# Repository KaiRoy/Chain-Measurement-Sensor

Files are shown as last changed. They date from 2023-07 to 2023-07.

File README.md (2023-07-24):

# Chain-Measurement-Sensor
The focus of this project was to create a Sensor that measures the wear of a chain for our Senior design course. The project partner for this project was the Hyster-Yale Group.

<!-- Insert Image Here -->

<!-- LINK SUMMARY VIDEO SOMEWHERE IN THE README!! -->

## Table of Contents

- [Description](#description)
- [Design](#design)
- [Current State](#current-state-of-the-project)
- [Post Project Notes](#post-project-notes)
- [Installation](#installation) <!-- Should I have Installation and Usage above or below the Design, Current State, Changes, etc? -->
- [Usage](#usage)
- [Credits](#credits)
- [License](#license)

## Description

The goal of this project is to create a chain elongation monitor for the Hyster-Yale Group that will automatically detect a worn lift chain and notify an operator to replace said chain. Chains, especially lifting chains, need to be frequently inspected to ensure they meet specifications. A 3% increase in a chain’s length can reduce its lifting capacity by 15%. This can become a dangerous hazard if out-of-spec chains are not caught. 

Currently, this inspection is either done by hand or by expensive third party devices, thus the creation of a cheap electronic alternative is very desirable. We plan to use three pairs of IR LEDs and IR receivers that will act as our sensors. These pairs will be situated in such a way that the IR “beam” will break when a chain link passes the sensor and reconnect in the gap between chain links. One pair will be used to measure the speed, while the other two will measure the “stretch” of the chain by recording the time difference between activations and calculating a length measurement.

In addition to the sensors, the device will consist of a power circuit to convert a Forklift’s 24V power into 5Vs, a CAN communication circuit, and a microcontroller to calculate the elongation based on the sensors and send those measurements via the CAN Circuit to the Hyster Vehicle. We chose an ATTiny814 for our microcontroller as it is a relatively small and cheap microcontroller and is capable of performing necessary functions, such as basic calculations and time measurement. 

Our project partner has specified that the device needs to meet four requirements:
 - The device needs to measure chain “stretch” (wear) within ±5% of the actual measurement.
 - The device, specifically the electronics, need to cost less than $15 or less at a production quantity of 15,000/yr
 - The device need to be robust enough to survive abrasive (high chain wear) applications
 - The device needs to communicate using the CAN communication protocol

At the end of our project, we were able to meet 3 of the 4 project partner requirements with the accuracy requirement being the one that was not met. This is mostly due to not having enough time to finish experimenting and debugging the code. With better time management and planning, we would have been able to finish the development of our code and could have met the final requirement.

## Designs

For the design portion of this project, the system's design was split into eight blocks with each person handling the design for two blocks. Adam handled the design of the Power Filter and the Power Regulator Blocks. Tianhao designed the Microcontroller and CAN Communication Circuits. The sensor and PCB blocks were handled by Kai. The code and the enclosure blocks were designed by Corbin. 

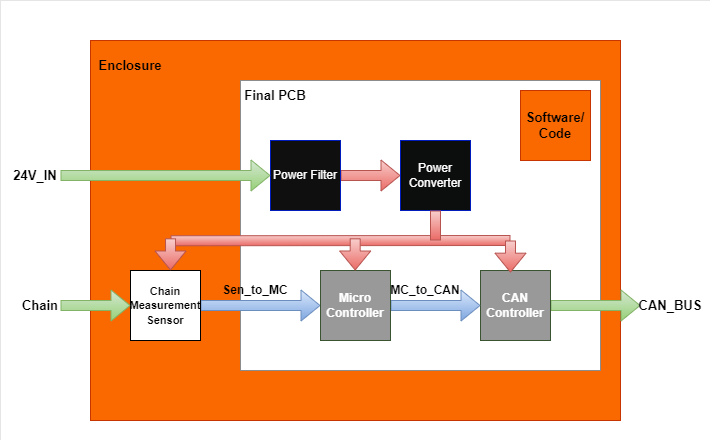
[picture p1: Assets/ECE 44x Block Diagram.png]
System Block Diagram


<!-- Power Blocks -->
The power converter block is based on an application schematic from the MC34063A-E datasheet to be used as a step-down converter. This block accomplishes the goal of reducing voltage and increasing current from 25V to 5V and current up to 500mA. The goal is to make the voltage and current levels safe for our microcontroller, CAN controller, and sensors to be used properly without overheating. The block contains the MC34063A/E chip itself, IN5819 Zener diode, three resistors (two are external to control the voltage output), three capacitors, and one inductor.

The power filter block is based on the LC filter schematic from [Digikey’s online LC filter calculator](https://www.digikey.com/en/resources/conversion-calculators/conversion-calculator-low-pass-and-high-pass-filter) to be used as a first order LC filter. This block accomplishes the goal of reducing frequency down to a fixed value of about less than 16kHz. This is to ensure that our high noise level of frequency is reduced so that our microcontroller and sensors can operate effectively. The block contains one inductor and one capacitor.

<!-- CAN Controller-->
The can block is built with one of the most practical stand-alone CAN controllers, MCP 2515 as the core. This module achieves the goal of communicating with Hyster Forklift’s electronics via 5 V digital serial signal. After achieving this goal, we can connect our device to the forklift with only two wires, so that the forklift can receive any information accurately. In this block, in addition to MCP 2515, we will also use TJA 1051 as the transceiver of the block to transmit or receive information transmitted through the CAN bus, an 8M Hz crystal oscillator as a bit rate regulator, an LED as an indicator, and some resistors and capacitors to stabilize the voltage and current of the part. In addition, we will also add two terminal block connectors to allow the output of the signal to adapt to more kinds of wires.

<!-- Micrcontroller -->
The Microcontroller block to be used in this project is the ATtiny 814. The module will be responsible for collecting and analyzing signals from the sensor, as well as controlling the operation of the signal transmitter. With the ATtiny 814, the project aims to achieve certain targets, such as measuring chain "stretch" within +/- 5% of the actual measurement, costing less than $10 at a production quantity of 15,000/yr, and outputting an analog (5V) or digital signal (CAN or other serial protocol signal).

<!-- Sensors -->
The Sensor block is implemented using three IR Breakbeam sensors. This document provides an overview of the overall block function including interface properties and a schematic, verification for the design in the form of a step-by-step testing process, and support for the validity of the design in the form of outside research and numerical justification addressing individual properties.

One sensor is placed in the ‘middle’ middle of the device and will be for measuring the speed of the Chain, while two sensors will be placed on the outer edges of the device and will be used for measuring/detecting the elongation of the chain.

The measurement of speed can be done by measuring the time difference between sensor activation as a chain link crosses the two central sensors and calculating the speed with that delta and the chain link length. For the elongation measurement/monitoring, the outer two sensors are placed with a specific distance between them, X amount of chain links. If positioned correctly, the two sensors will activate simultaneously with a chain that is not elongated and activates with some time delta with a chain that is elongated. This time delta coupled with the calculated speed can provide an estimate for the elongation measurement.

<!-- PCB -->
The Final PCB contains most of the circuits for all of the electronics blocks of the system. These circuits include the Power Filter, Power Converter, Microcontroller, and CAN Controller Blocks. This means that all of the outward-facing interfaces for these blocks, such as the sensor, power, and CAN connectors, are the interfaces for this block. 

<!-- Enclosure -->
The enclosure for this project will be a durable Pelican Case, created and distributed by the Pelican company. This ensures that our enclosure will be consistent, professionally made, and strong enough to protect our fragile components from the dangerous environment they will have to be in. Additionally, a piece of acrylic will be laser cut to allow for the mounting of the PCB and the guiding of wires through the walls of the enclosure, which will have holes cut into it.

## Current State of the Project

By the end of the project, we had a mostly working system. 

## Post Project Notes

## Installation

What EDA libraries and files are needed for this project?
- Various Component Libraries

<!--
## Usage

Provide instructions and examples for use. Include screenshots as needed.

To add a screenshot, create an `assets/images` folder in your repository and upload your screenshot to it. Then, using the relative filepath, add it to your README using the following syntax:

    ```md
    ![alt text](assets/images/screenshot.png)
    ```

## Features

If your project has a lot of features, list them here.

## Tests

-->

## Credits

List your collaborators, if any, with links to their GitHub profiles.
- Kai Roy
- 

If you used any third-party assets that require attribution, list the creators with links to their primary web presence in this section.
-

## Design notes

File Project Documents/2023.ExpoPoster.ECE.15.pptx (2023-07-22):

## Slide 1

ECE.15

Engineering Requirements

The System will…
- PCB - Have a single PCB that is no larger than 6 inches squared and contains all non-sensor circuits.
- Power Input - Operate on 24VDC with up to 3Vpp of noise and 500mA peak of current.
- Project Partner Checkoff - Be approved by a Hyster-Yale electrical engineer (project partner).
- Robust Enclosure - Continue to operate at designed accuracy after 250 chain rotations.
- Sensor Accuracy - Measure chain “stretch” within +/- 5% of the actual value.
- Signal Output - Communicate with the Hyster Forklift’s electronics using a 5V digital serial signal.
- System Cost - Cost less than $15 at a production quantity of 15,000/yr, including the enclosure.
- Water Resistance - Function normally after applying a 12oz bottle of water from above.

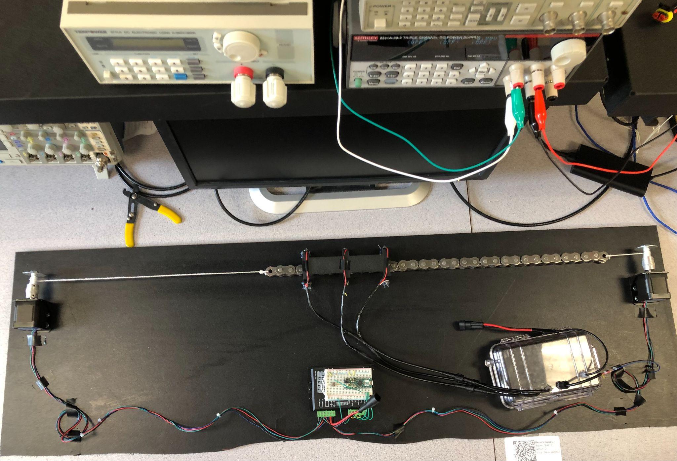
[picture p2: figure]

Fig. 4. Test bench used to determine the accuracy and durability of the system

Forklift Chain “Stretch” Monitor

Non-Contact Sensor to Determine Chain Wear for Heavy Duty Applications

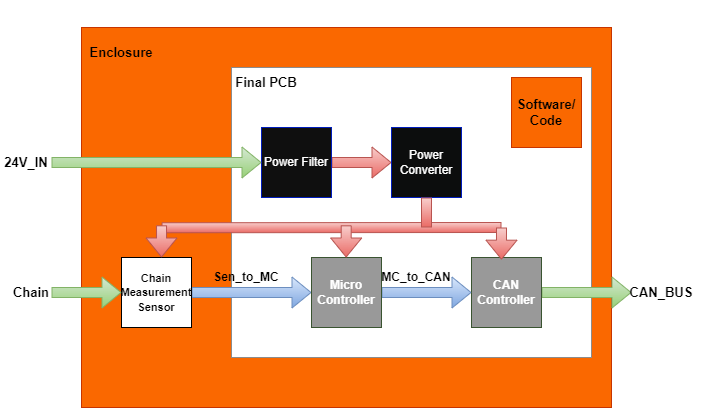
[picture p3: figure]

Fig. 1. Block diagram of the system

Project Summary

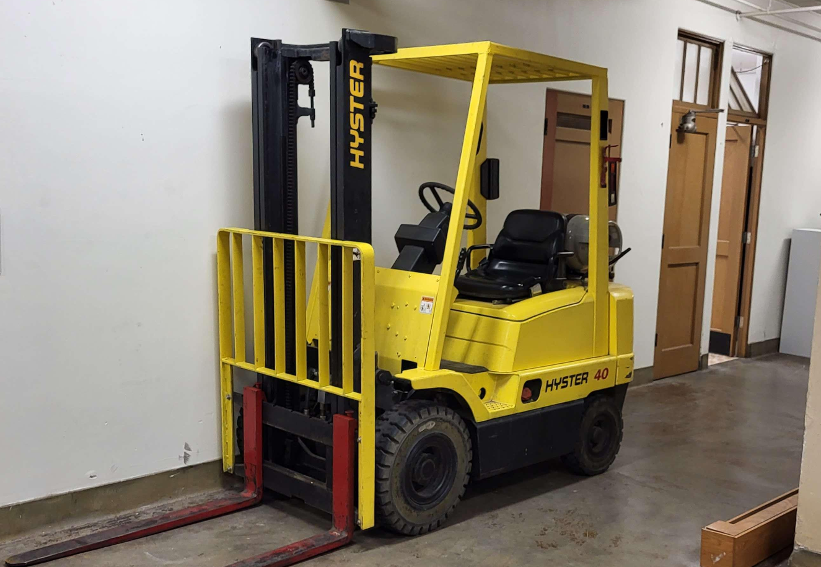
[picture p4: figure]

Fig. 5. Hyster Forklift

Our project is intended to determine whether it is feasible to create a reliable chain wear detection device that is economical. Hyster-Yale currently uses chain wear detection devies and our goal was to create a proof of concept that Hyster-Yale can obtain and improve upon.

CAN Controller

- The Controller Area Network (CAN) is one way of facilitating communication between electronic components
- CAN is a standard communication system in vehicles and allows for different sensors and components to communicate on the same line/bus in a priority-driven manner
- Many modern vehicles, and importantly Hyster Yale forklifts, use CAN controls
- Information from more crucial components is transmitted before other, less important devices all on the same network

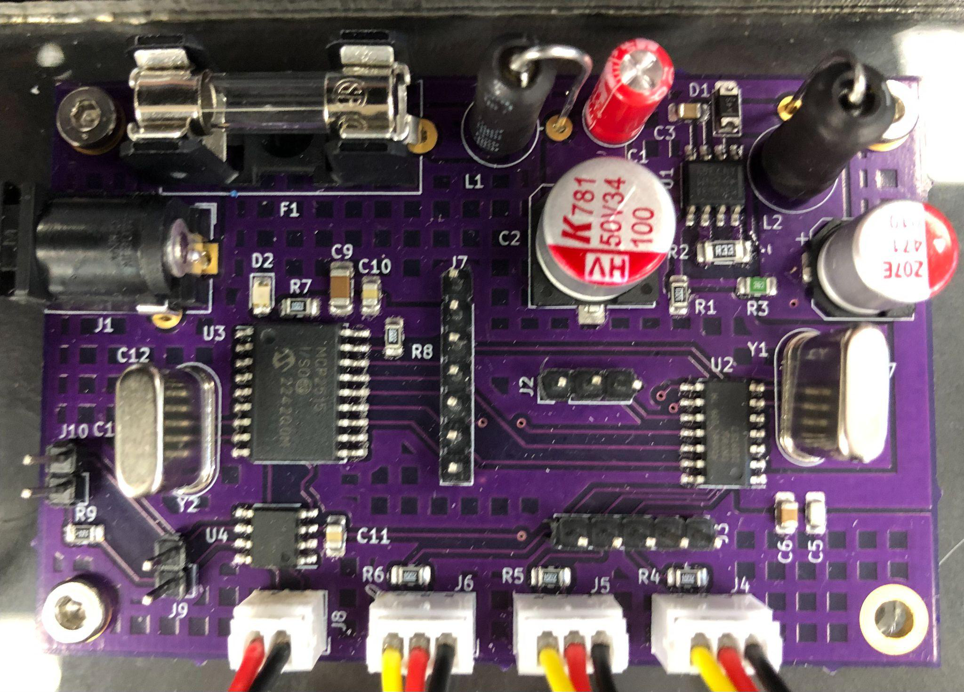
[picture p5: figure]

Fig. 2. Assembled PCB

Chain Measurement Sensor

- Three IR Break beam Sensors are used to measure Chain Elongation
- One sensor is used to measure speed, which the others are used to measure the elongation
- The timing difference between the sensors coupled with the speed gives us the elongation
- A 3D Bracket was designed for the sensors to keep the distance between them both constant and known for the measurement calculations

Enclosure

- Our enclosure consists of a pelican case with an acrylic plate for the custom PCB and holes drilled and then sealed to allow for waterproof cables to be added to the system. These cables connect to the Power, CAN, and sensors.

Power Filter/Converter

- Power supply with input from 24V battery
- Operates between 21-27VDC and up to but not including 500mA of current
- Uses a step-down converter (buck converter) to step down voltage and filter (LC) noise from the battery
- Efficiency rated between 66-80%. Efficiencies vary based on current
- Can replace fuse for circuit protection from current spikes from the battery

Team Members

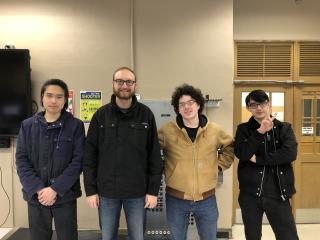
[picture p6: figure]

Fig. 6. All four members

(From left to right)
Tianhao Lin:
Microcontroller/CAN Controller Designer
lintia@oregonstate.edu
Adam Grzelewski:
Power Converter/Filter Designer
grzelewa@oregonstate.edu
Corbin Krecklow:
Programmer and Enclosure Designer
kreckloc@oregonstate.edu
Kai Roy:
Sensor and PCB Design
kaikurisakaroy@gmail.com

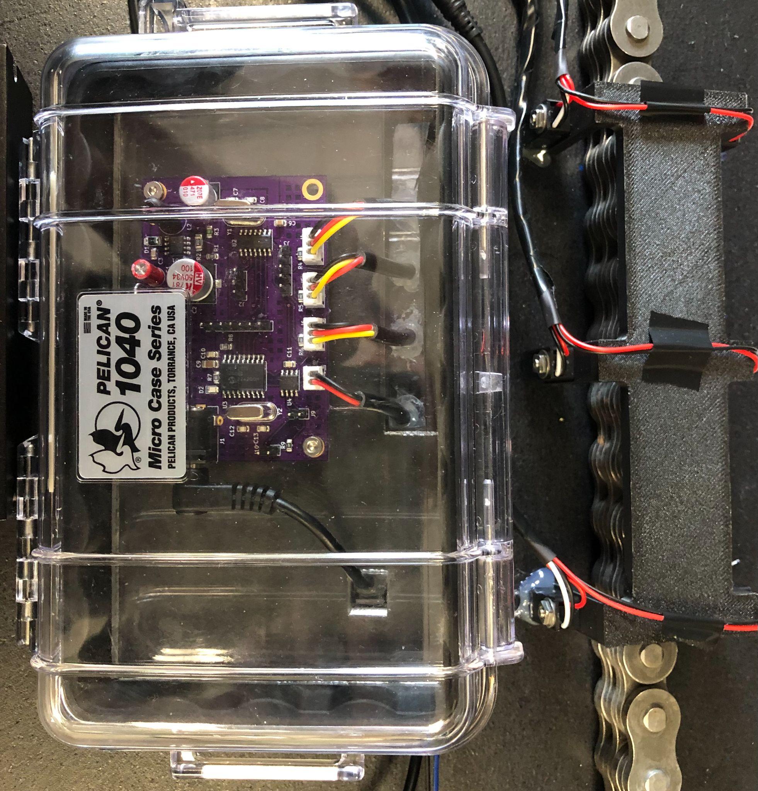
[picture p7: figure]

Fig. 3. Sensors bracket and PCB enclosure

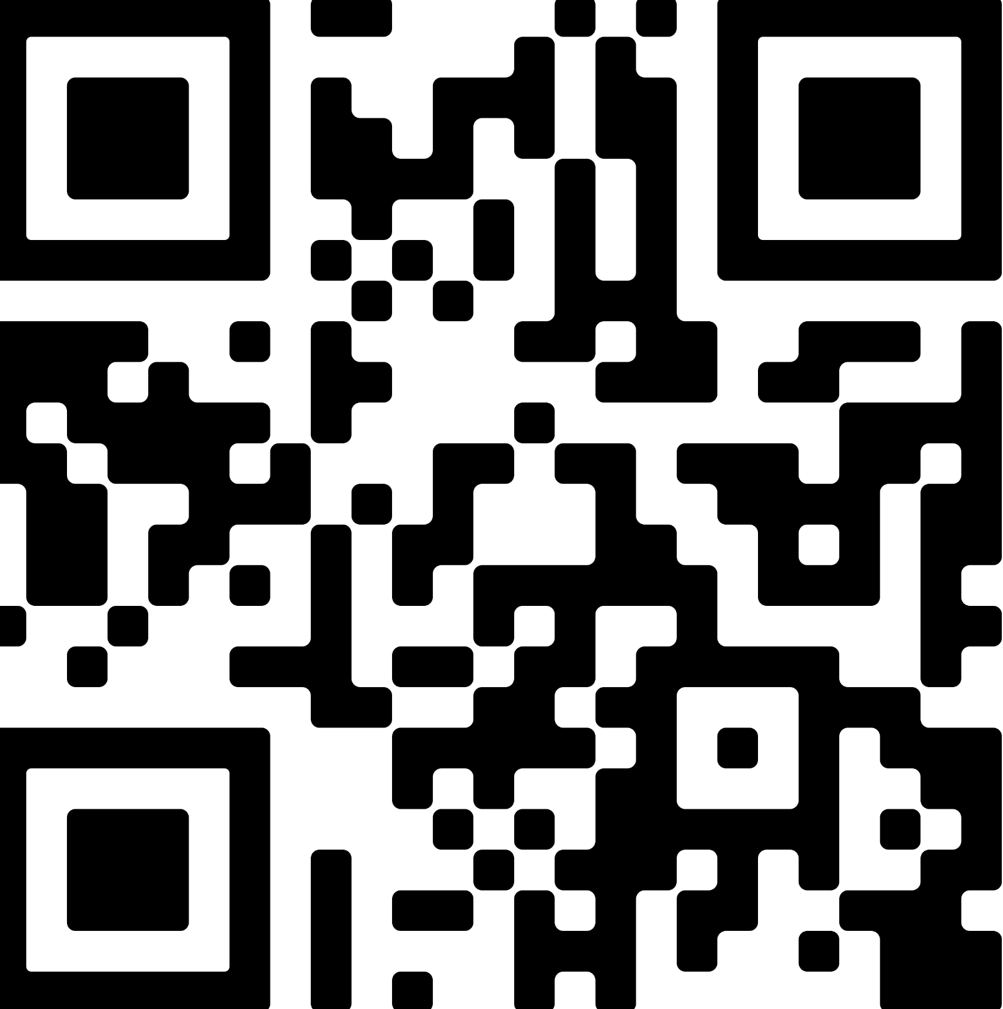
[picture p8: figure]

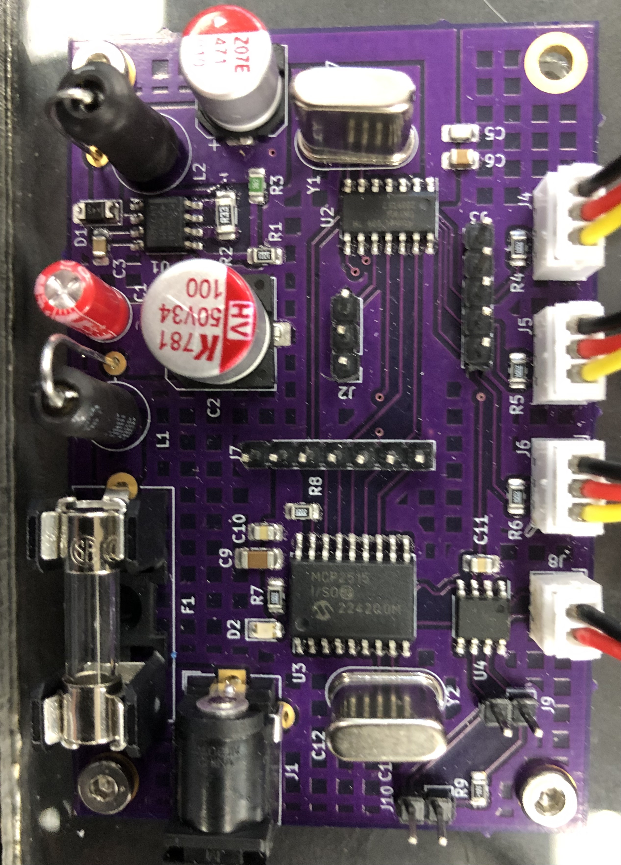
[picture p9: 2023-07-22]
Assets/PCB.jpg

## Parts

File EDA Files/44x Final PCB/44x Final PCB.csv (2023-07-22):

Source: | C:\Users\Kai Roy\Desktop\ECE 44x\44x Final PCB\44x Final PCB.kicad_sch
Date: | 2/22/2023 10:40:46 PM
Tool: | Eeschema (6.0.1)
Generator: | C:\Program Files\KiCad\6.0\bin\scripting\plugins/bom_csv_grouped_by_value.py
Component Count: | 47
Individual Components:
Item | Qty | Reference(s) | Value | LibPart | Footprint | Datasheet | Digikey | Mouser
 |  | C1 | 1uF | Device:C_Small | Capacitor_THT:C_Radial_D5.0mm_H11.0mm_P2.00mm | https://www.mouser.com/ProductDetail/Wurth-Elektronik/860020672005?qs=0KOYDY2FL29w5cS8aahRvQ%3D%3D |  | 710-860020672005
 |  | C2 | 100uF | Device:C_Small | Capacitor_SMD:C_Elec_10x10.2 | https://www.mouser.com/ProductDetail/KEMET/A781MN107M1HLAS030 |  | 80-A781MN107M1HLAS30
 |  | C3 | 470pF | Device:C_Small | Capacitor_SMD:C_0805_2012Metric_Pad1.18x1.45mm_HandSolder | ~ |  | 581-0805YC471K
 |  | C4 | 470uF | Device:C_Small | Capacitor_SMD:CP_Elec_8x10 | https://www.mouser.com/ProductDetail/KYOCERA-AVX/APZ0809471M010R |  | 581-APZ0809471M010R
 |  | C5 | 22pF | Device:C_Small | Capacitor_SMD:C_0805_2012Metric_Pad1.18x1.45mm_HandSolder | ~ |  | 80-C0805C220J4HACTU
 |  | C6 | 4.7uF | Device:C_Small | Capacitor_SMD:C_0805_2012Metric_Pad1.18x1.45mm_HandSolder | ~ |  | 81-GCJ21BR71C475KA1L
 |  | C7 | 22pF | Device:C_Small | Capacitor_SMD:C_0805_2012Metric_Pad1.18x1.45mm_HandSolder | ~ |  | 80-C0805C220J4HACTU
 |  | C8 | 22pF | Device:C_Small | Capacitor_SMD:C_0805_2012Metric_Pad1.18x1.45mm_HandSolder | ~ |  | 80-C0805C220J4HACTU
 |  | C9 | 10uF/16V | Device:C_Polarized | Capacitor_SMD:C_1206_3216Metric_Pad1.33x1.80mm_HandSolder | https://product.tdk.com/system/files/dam/doc/product/capacitor/ceramic/mlcc/catalog/mlcc_commercial_general_en.pdf |  | 80-C1206C106Z4VACTU
 |  | C10 | 100nF | Device:C_Small | Capacitor_SMD:C_0805_2012Metric_Pad1.18x1.45mm_HandSolder | ~ |  | 581-0805YC104M4T2A
 |  | C11 | 100nF | Device:C_Small | Capacitor_SMD:C_0805_2012Metric_Pad1.18x1.45mm_HandSolder | ~ |  | 581-0805YC104M4T2A
 |  | C12 | 22pF | Device:C_Small | Capacitor_SMD:C_0805_2012Metric_Pad1.18x1.45mm_HandSolder | ~ |  | 80-C0805C220J4HACTU
 |  | C13 | 22pF | Device:C_Small | Capacitor_SMD:C_0805_2012Metric_Pad1.18x1.45mm_HandSolder | ~ |  | 80-C0805C220J4HACTU
 |  | D1 | Schottky | Device:D | Diode_SMD:D_1206_3216Metric_Pad1.42x1.75mm_HandSolder | ~ |  | 581-SD1206T040S1R0
 |  | D2 | RED | Device:LED_Small_Filled | LED_SMD:LED_0805_2012Metric_Pad1.15x1.40mm_HandSolder | https://optoelectronics.liteon.com/upload/download/DS22-2000-223/LTST-C191KRKT.PDF | LTST-C191KRKT | 720-LSR976-NR-1
 |  | F1 | Fuse | Device:Fuse | Fuse:Fuseholder_Cylinder-5x20mm_Schurter_0031_8201_Horizontal_Open | ~ |  | 693-0031.8201
 |  | H1 | MountingHole_Pad | Mechanical:MountingHole_Pad | MountingHole:MountingHole_3.2mm_M3_ISO14580_Pad_TopBottom | ~
 |  | H2 | MountingHole_Pad | Mechanical:MountingHole_Pad | MountingHole:MountingHole_3.2mm_M3_ISO14580_Pad_TopBottom | ~
 |  | H3 | MountingHole_Pad | Mechanical:MountingHole_Pad | MountingHole:MountingHole_3.2mm_M3_ISO14580_Pad_TopBottom | ~
 |  | H4 | MountingHole_Pad | Mechanical:MountingHole_Pad | MountingHole:MountingHole_3.2mm_M3_ISO14580_Pad_TopBottom | ~
 |  | J1 | Barrel_Jack | Connector:Barrel_Jack_MountingPin | Connector_BarrelJack:BarrelJack_CUI_PJ-102AH_Horizontal | ~ |  | 490-PJ-102AH
 |  | J2 | Conn_01x03 | Connector_Generic:Conn_01x03 | Connector_PinHeader_2.54mm:PinHeader_1x03_P2.54mm_Vertical | ~
 |  | J3 | Conn_01x05 | Connector_Generic:Conn_01x05 | Connector_PinHeader_2.54mm:PinHeader_1x05_P2.54mm_Vertical | ~
 |  | J4 | Conn_01x03 | Connector_Generic:Conn_01x03 | Connector_JST:JST_PH_B3B-PH-K_1x03_P2.00mm_Vertical | ~
 |  | J5 | Conn_01x03 | Connector_Generic:Conn_01x03 | Connector_JST:JST_PH_B3B-PH-K_1x03_P2.00mm_Vertical | ~
 |  | J6 | Conn_01x03 | Connector_Generic:Conn_01x03 | Connector_JST:JST_PH_B3B-PH-K_1x03_P2.00mm_Vertical | ~
 |  | J7 | Conn_01x07 | Connector_Generic:Conn_01x07 | Connector_PinHeader_2.54mm:PinHeader_1x07_P2.54mm_Vertical | ~
 |  | J8 | Conn_01x02 | Connector_Generic:Conn_01x02 | Connector_JST:JST_PH_B2B-PH-K_1x02_P2.00mm_Vertical | ~
 |  | J9 | Conn_01x02 | Connector_Generic:Conn_01x02 | Connector_PinHeader_2.54mm:PinHeader_1x02_P2.54mm_Vertical | ~
 |  | J10 | Conn_01x02 | Connector_Generic:Conn_01x02 | Connector_PinHeader_2.54mm:PinHeader_1x02_P2.54mm_Vertical | ~
 |  | L1 | 100uH | Device:L_Small | Inductor_THT:L_Axial_L16.0mm_D6.3mm_P5.08mm_Vertical_Fastron_VHBCC | https://www.mouser.com/ProductDetail/Bel-Signal-Transformer/SFAPI-101K-UL?qs=rQFj71Wb1eU2GmpN%2Fg520g%3D%3D |  | 530-SFAPI-101K-UL
 |  | L2 | 220uH | Device:L_Small | Inductor_THT:L_Axial_L16.0mm_D7.5mm_P5.08mm_Vertical_Fastron_XHBCC | https://www.mouser.com/ProductDetail/Bourns/5800-221-RC?qs=UhUgWT7Q6Vt8RYxRyMV0zA%3D%3D |  | 542-5800-221-RC
 |  | R1 | 1.2kR | Device:R_Small | Resistor_SMD:R_0805_2012Metric_Pad1.20x1.40mm_HandSolder | ~ |  | 667-ERJ-PB6B1201V
 |  | R2 | 330mR | Device:R_Small | Resistor_SMD:R_1206_3216Metric_Pad1.30x1.75mm_HandSolder | https://www.mouser.com/ProductDetail/Wurth-Elektronik/561070332096?qs=unwgFEO1A6tnpCUDyqbJ0g%3D%3D |  | 710-561070332096
 |  | R3 | 3.6kR | Device:R_Small | Resistor_SMD:R_0805_2012Metric_Pad1.20x1.40mm_HandSolder | ~ |  | 667-ERJ-PB6B3601V
 |  | R4 | 10kR | Device:R_Small | Resistor_SMD:R_0805_2012Metric_Pad1.20x1.40mm_HandSolder | ~ |  | 667-ERJ-PB6B1002V
 |  | R5 | 10kR | Device:R_Small | Resistor_SMD:R_0805_2012Metric_Pad1.20x1.40mm_HandSolder | ~ |  | 667-ERJ-PB6B1002V
 |  | R6 | 10kR | Device:R_Small | Resistor_SMD:R_0805_2012Metric_Pad1.20x1.40mm_HandSolder | ~ |  | 667-ERJ-PB6B1002V
 |  | R7 | 1kR | Device:R_Small | Resistor_SMD:R_0805_2012Metric_Pad1.20x1.40mm_HandSolder | ~ |  | 667-ERJ-PB6B1001V
 |  | R8 | 10kR | Device:R_Small | Resistor_SMD:R_0805_2012Metric_Pad1.20x1.40mm_HandSolder | ~ |  | 667-ERJ-PB6B1002V
 |  | R9 | 120R | Device:R | Resistor_SMD:R_0805_2012Metric_Pad1.20x1.40mm_HandSolder | ~ |  | 667-ERJ-T06J121V
 |  | U1 | MC34063AE | MC34063AE:MC34063AE | Package_SO:SOIC-8_3.9x4.9mm_P1.27mm |  |  | 595-MC34063ADR
 |  | U2 | ATtiny814-SS | MCU_Microchip_ATtiny:ATtiny814-SS | Package_SO:SOIC-14_3.9x8.7mm_P1.27mm | http://ww1.microchip.com/downloads/en/DeviceDoc/40001912A.pdf |  | 579-ATTINY814-SSN
 |  | U3 | MCP2515-xSO | Interface_CAN_LIN:MCP2515-xSO | Package_SO:SOIC-18W_7.5x11.6mm_P1.27mm | http://ww1.microchip.com/downloads/en/DeviceDoc/21801e.pdf |  | 579-MCP2515-I/SO
 |  | U4 | TJA1051T | Interface_CAN_LIN:TJA1051T | Package_SO:SOIC-8_3.9x4.9mm_P1.27mm | http://www.nxp.com/documents/data_sheet/TJA1051.pdf |  | 771-TJA1051T3118
 |  | Y1 | 8MHz | Device:Crystal | Crystal:Crystal_HC49-U_Vertical | https://ecsxtal.com/store/pdf/csm-7x.pdf |  | 520-HCA800-18
 |  | Y2 | 8MHz | Device:Crystal | Crystal:Crystal_HC49-U_Vertical | https://ecsxtal.com/store/pdf/csm-7x.pdf |  | 520-HCA800-18
Collated Components:
Item | Qty | Reference(s) | Value | LibPart | Footprint | Datasheet | Digikey | Mouser
1 | 1 | C1 | 1uF | Device:C_Small | Capacitor_THT:C_Radial_D5.0mm_H11.0mm_P2.00mm | https://www.mouser.com/ProductDetail/Wurth-Elektronik/860020672005?qs=0KOYDY2FL29w5cS8aahRvQ%3D%3D |  | 710-860020672005
2 | 1 | C2 | 100uF | Device:C_Small | Capacitor_SMD:C_Elec_10x10.2 | https://www.mouser.com/ProductDetail/KEMET/A781MN107M1HLAS030 |  | 80-A781MN107M1HLAS30
3 | 1 | C3 | 470pF | Device:C_Small | Capacitor_SMD:C_0805_2012Metric_Pad1.18x1.45mm_HandSolder | ~ |  | 581-0805YC471K
4 | 1 | C4 | 470uF | Device:C_Small | Capacitor_SMD:CP_Elec_8x10 | https://www.mouser.com/ProductDetail/KYOCERA-AVX/APZ0809471M010R |  | 581-APZ0809471M010R
5 | 5 | C5, C7, C8, C12, C13 | 22pF | Device:C_Small | Capacitor_SMD:C_0805_2012Metric_Pad1.18x1.45mm_HandSolder | ~ |  | 80-C0805C220J4HACTU
6 | 1 | C6 | 4.7uF | Device:C_Small | Capacitor_SMD:C_0805_2012Metric_Pad1.18x1.45mm_HandSolder | ~ |  | 81-GCJ21BR71C475KA1L
7 | 1 | C9 | 10uF/16V | Device:C_Polarized | Capacitor_SMD:C_1206_3216Metric_Pad1.33x1.80mm_HandSolder | https://product.tdk.com/system/files/dam/doc/product/capacitor/ceramic/mlcc/catalog/mlcc_commercial_general_en.pdf |  | 80-C1206C106Z4VACTU
8 | 2 | C10, C11 | 100nF | Device:C_Small | Capacitor_SMD:C_0805_2012Metric_Pad1.18x1.45mm_HandSolder | ~ |  | 581-0805YC104M4T2A
9 | 1 | D1 | Schottky | Device:D | Diode_SMD:D_1206_3216Metric_Pad1.42x1.75mm_HandSolder | ~ |  | 581-SD1206T040S1R0
10 | 1 | D2 | RED | Device:LED_Small_Filled | LED_SMD:LED_0805_2012Metric_Pad1.15x1.40mm_HandSolder | https://optoelectronics.liteon.com/upload/download/DS22-2000-223/LTST-C191KRKT.PDF | LTST-C191KRKT | 720-LSR976-NR-1
11 | 1 | F1 | Fuse | Device:Fuse | Fuse:Fuseholder_Cylinder-5x20mm_Schurter_0031_8201_Horizontal_Open | ~ |  | 693-0031.8201
12 | 4 | H1, H2, H3, H4 | MountingHole_Pad | Mechanical:MountingHole_Pad | MountingHole:MountingHole_3.2mm_M3_ISO14580_Pad_TopBottom | ~
13 | 1 | J1 | Barrel_Jack | Connector:Barrel_Jack_MountingPin | Connector_BarrelJack:BarrelJack_CUI_PJ-102AH_Horizontal | ~ |  | 490-PJ-102AH
14 | 1 | J2 | Conn_01x03 | Connector_Generic:Conn_01x03 | Connector_PinHeader_2.54mm:PinHeader_1x03_P2.54mm_Vertical | ~
15 | 1 | J3 | Conn_01x05 | Connector_Generic:Conn_01x05 | Connector_PinHeader_2.54mm:PinHeader_1x05_P2.54mm_Vertical | ~
16 | 3 | J4, J5, J6 | Conn_01x03 | Connector_Generic:Conn_01x03 | Connector_JST:JST_PH_B3B-PH-K_1x03_P2.00mm_Vertical | ~
17 | 1 | J7 | Conn_01x07 | Connector_Generic:Conn_01x07 | Connector_PinHeader_2.54mm:PinHeader_1x07_P2.54mm_Vertical | ~
18 | 1 | J8 | Conn_01x02 | Connector_Generic:Conn_01x02 | Connector_JST:JST_PH_B2B-PH-K_1x02_P2.00mm_Vertical | ~
19 | 2 | J9, J10 | Conn_01x02 | Connector_Generic:Conn_01x02 | Connector_PinHeader_2.54mm:PinHeader_1x02_P2.54mm_Vertical | ~
20 | 1 | L1 | 100uH | Device:L_Small | Inductor_THT:L_Axial_L16.0mm_D6.3mm_P5.08mm_Vertical_Fastron_VHBCC | https://www.mouser.com/ProductDetail/Bel-Signal-Transformer/SFAPI-101K-UL?qs=rQFj71Wb1eU2GmpN%2Fg520g%3D%3D |  | 530-SFAPI-101K-UL
21 | 1 | L2 | 220uH | Device:L_Small | Inductor_THT:L_Axial_L16.0mm_D7.5mm_P5.08mm_Vertical_Fastron_XHBCC | https://www.mouser.com/ProductDetail/Bourns/5800-221-RC?qs=UhUgWT7Q6Vt8RYxRyMV0zA%3D%3D |  | 542-5800-221-RC
22 | 1 | R1 | 1.2kR | Device:R_Small | Resistor_SMD:R_0805_2012Metric_Pad1.20x1.40mm_HandSolder | ~ |  | 667-ERJ-PB6B1201V
23 | 1 | R2 | 330mR | Device:R_Small | Resistor_SMD:R_1206_3216Metric_Pad1.30x1.75mm_HandSolder | https://www.mouser.com/ProductDetail/Wurth-Elektronik/561070332096?qs=unwgFEO1A6tnpCUDyqbJ0g%3D%3D |  | 710-561070332096
24 | 1 | R3 | 3.6kR | Device:R_Small | Resistor_SMD:R_0805_2012Metric_Pad1.20x1.40mm_HandSolder | ~ |  | 667-ERJ-PB6B3601V
25 | 4 | R4, R5, R6, R8 | 10kR | Device:R_Small | Resistor_SMD:R_0805_2012Metric_Pad1.20x1.40mm_HandSolder | ~ |  | 667-ERJ-PB6B1002V
26 | 1 | R7 | 1kR | Device:R_Small | Resistor_SMD:R_0805_2012Metric_Pad1.20x1.40mm_HandSolder | ~ |  | 667-ERJ-PB6B1001V
27 | 1 | R9 | 120R | Device:R | Resistor_SMD:R_0805_2012Metric_Pad1.20x1.40mm_HandSolder | ~ |  | 667-ERJ-T06J121V
28 | 1 | U1 | MC34063AE | MC34063AE:MC34063AE | Package_SO:SOIC-8_3.9x4.9mm_P1.27mm |  |  | 595-MC34063ADR
29 | 1 | U2 | ATtiny814-SS | MCU_Microchip_ATtiny:ATtiny814-SS | Package_SO:SOIC-14_3.9x8.7mm_P1.27mm | http://ww1.microchip.com/downloads/en/DeviceDoc/40001912A.pdf |  | 579-ATTINY814-SSN
30 | 1 | U3 | MCP2515-xSO | Interface_CAN_LIN:MCP2515-xSO | Package_SO:SOIC-18W_7.5x11.6mm_P1.27mm | http://ww1.microchip.com/downloads/en/DeviceDoc/21801e.pdf |  | 579-MCP2515-I/SO
31 | 1 | U4 | TJA1051T | Interface_CAN_LIN:TJA1051T | Package_SO:SOIC-8_3.9x4.9mm_P1.27mm | http://www.nxp.com/documents/data_sheet/TJA1051.pdf |  | 771-TJA1051T3118
32 | 2 | Y1, Y2 | 8MHz | Device:Crystal | Crystal:Crystal_HC49-U_Vertical | https://ecsxtal.com/store/pdf/csm-7x.pdf |  | 520-HCA800-18

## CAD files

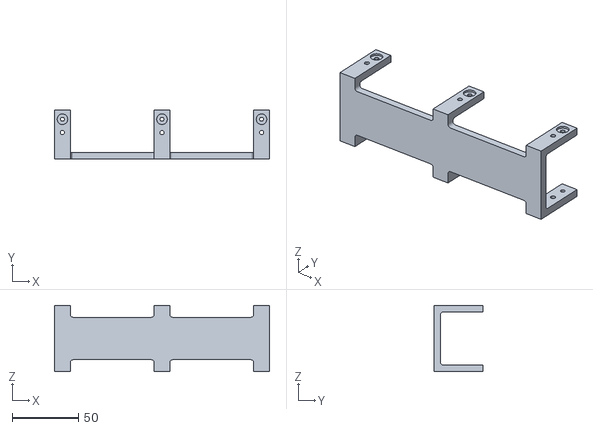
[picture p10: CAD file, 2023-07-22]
CAD Files/sensor_bracket_v2.stl
162.0 x 37.0 x 50.0

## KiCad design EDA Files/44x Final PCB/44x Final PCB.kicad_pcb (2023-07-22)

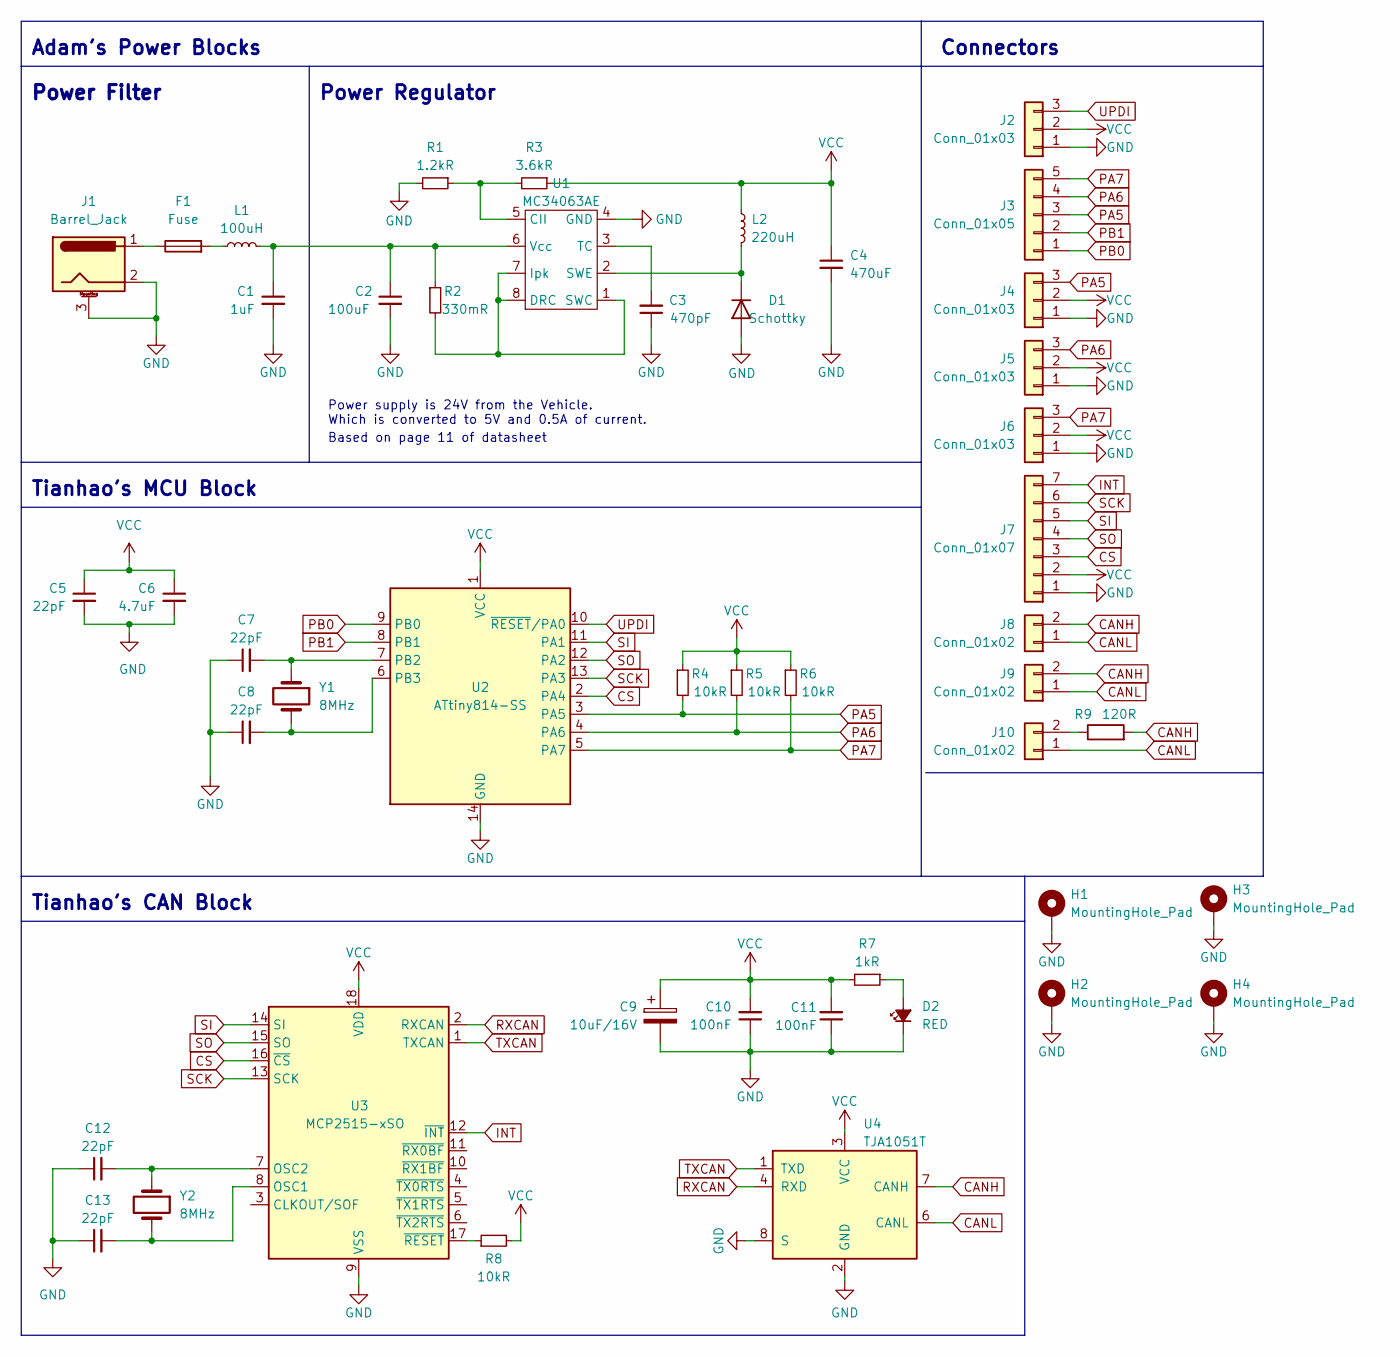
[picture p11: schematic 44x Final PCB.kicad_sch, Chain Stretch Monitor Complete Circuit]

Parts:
C1: 1uF; C_Radial_D5.0mm_H11.0mm_P2.00mm; Mouser 710-860020672005
C2: 100uF; C_Elec_10x10.2; Mouser 80-A781MN107M1HLAS30
C3: 470pF; C_0805_2012Metric_Pad1.18x1.45mm_HandSolder; Mouser 581-0805YC471K
C4: 470uF; CP_Elec_8x10; Mouser 581-APZ0809471M010R
C5, C7, C8, C12, C13: 22pF; C_0805_2012Metric_Pad1.18x1.45mm_HandSolder; Mouser 80-C0805C220J4HACTU
C6: 4.7uF; C_0805_2012Metric_Pad1.18x1.45mm_HandSolder; Mouser 81-GCJ21BR71C475KA1L
C9: 10uF/16V; C_1206_3216Metric_Pad1.33x1.80mm_HandSolder; Mouser 80-C1206C106Z4VACTU
C10, C11: 100nF; C_0805_2012Metric_Pad1.18x1.45mm_HandSolder; Mouser 581-0805YC104M4T2A
D1: Schottky; D_1206_3216Metric_Pad1.42x1.75mm_HandSolder; Mouser 581-SD1206T040S1R0
D2: RED; LED_0805_2012Metric_Pad1.15x1.40mm_HandSolder; Digikey LTST-C191KRKT
F1: Fuse; Fuseholder_Cylinder-5x20mm_Schurter_0031_8201_Horizontal_Op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; Mouser 693-0031.8201
H1, H2, H3, H4: MountingHole_Pad; MountingHole_3.2mm_M3_ISO14580_Pad_TopBottom
J1: Barrel_Jack; BarrelJack_CUI_PJ-102AH_Horizontal; Mouser 490-PJ-102AH
J2: Conn_01x03; PinHeader_1x03_P2.54mm_Vertical
J3: Conn_01x05; PinHeader_1x05_P2.54mm_Vertical
J4, J5, J6: Conn_01x03; JST_PH_B3B-PH-K_1x03_P2.00mm_Vertical
J7: Conn_01x07; PinHeader_1x07_P2.54mm_Vertical
J8: Conn_01x02; JST_PH_B2B-PH-K_1x02_P2.00mm_Vertical
J9, J10: Conn_01x02; PinHeader_1x02_P2.54mm_Vertical
L1: 100uH; L_Axial_L16.0mm_D6.3mm_P5.08mm_Vertical_Fastron_VHBCC; Mouser 530-SFAPI-101K-UL
L2: 220uH; L_Axial_L16.0mm_D7.5mm_P5.08mm_Vertical_Fastron_XHBCC; Mouser 542-5800-221-RC
R1: 1.2kR; R_0805_2012Metric_Pad1.20x1.40mm_HandSolder; Mouser 667-ERJ-PB6B1201V
R2: 330mR; R_1206_3216Metric_Pad1.30x1.75mm_HandSolder; Mouser 710-561070332096
R3: 3.6kR; R_0805_2012Metric_Pad1.20x1.40mm_HandSolder; Mouser 667-ERJ-PB6B3601V
R4, R5, R6, R8: 10kR; R_0805_2012Metric_Pad1.20x1.40mm_HandSolder; Mouser 667-ERJ-PB6B1002V
R7: 1kR; R_0805_2012Metric_Pad1.20x1.40mm_HandSolder; Mouser 667-ERJ-PB6B1001V
R9: 120R; R_0805_2012Metric_Pad1.20x1.40mm_HandSolder; Mouser 667-ERJ-T06J121V
U1: MC34063AE; SOIC-8_3.9x4.9mm_P1.27mm; Mouser 595-MC34063ADR
U2: ATtiny814-SS; SOIC-14_3.9x8.7mm_P1.27mm; Mouser 579-ATTINY814-SSN
U3: MCP2515-xSO; SOIC-18W_7.5x11.6mm_P1.27mm; Mouser 579-MCP2515-I/SO
U4: TJA1051T; SOIC-8_3.9x4.9mm_P1.27mm; Mouser 771-TJA1051T3118
Y1, Y2: 8MHz; Crystal_HC49-U_Vertical; Mouser 520-HCA800-18

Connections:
CANH: J8.2, J9.2, R9.2, U4.7 (CANH)
CANL: J8.1, J9.1, J10.1, U4.6 (CANL)
CS: J7.3, U2.2 (PA4), U3.16 (~CS)
GND: C1.2, C2.2, C3.1, C4.2, C5.2, C6.2, C7.1, C8.1, C9.2, C10.1, C11.1, C12.1, C13.1, D1.2 (A), D2.1 (K), H1.1, H2.1, H3.1, H4.1, J1.2, J1.3 (MountPin), J2.1, J4.1, J5.1, J6.1, J7.1, R1.2, U1.4 (GND), U2.14 (GND), U3.9 (VSS), U4.2 (GND), U4.8 (S)
INT: J7.7, U3.12 (~INT)
unnamed: C1.1, C2.1, L1.2, R2.1, U1.6 (Vcc)
unnamed: C3.2, U1.3 (TC)
unnamed: C7.2, U2.7 (PB2), Y1.1
unnamed: C8.2, U2.6 (PB3), Y1.2
unnamed: C12.2, U3.7 (OSC2), Y2.1
unnamed: C13.2, U3.8 (OSC1), Y2.2
unnamed: D1.1 (K), L2.2, U1.2 (SWE)
unnamed: D2.2 (A), R7.1
unnamed: F1.1, J1.1
unnamed: F1.2, L1.1
unnamed: J10.2, R9.1
unnamed: R1.1, R3.2, U1.5 (CII)
unnamed: R2.2, U1.1 (SWC), U1.7 (Ipk), U1.8 (DRC)
unnamed: R8.1, U3.17 (~RESET)
PA5: J3.3, J4.3, R4.2, U2.3 (PA5)
PA6: J3.4, J5.3, R5.2, U2.4 (PA6)
PA7: J3.5, J6.3, R6.2, U2.5 (PA7)
PB0: J3.1, U2.9 (PB0)
PB1: J3.2, U2.8 (PB1)
RXCAN: U3.2 (RXCAN), U4.4 (RXD)
SCK: J7.6, U2.13 (PA3), U3.13 (SCK)
SI: J7.5, U2.11 (PA1), U3.14 (SI)
SO: J7.4, U2.12 (PA2), U3.15 (SO)
TXCAN: U3.1 (TXCAN), U4.1 (TXD)
UPDI: J2.3, U2.10 (~RESET/PA0)
VCC: C4.1, C5.1, C6.1, C9.1, C10.2, C11.2, J2.2, J4.2, J5.2, J6.2, J7.2, L2.1, R3.1, R4.1, R5.1, R6.1, R7.2, R8.2, U2.1 (VCC), U3.18 (VDD), U4.3 (VCC)

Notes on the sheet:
Power Filter
Tianhao's MCU Block
Adam's Power Blocks
Tianhao's CAN Block
Power supply is 24V from the Vehicle. Which is converted to 5V and 0.5A of current.
Power Regulator
Connectors
Based on page 11 of datasheet

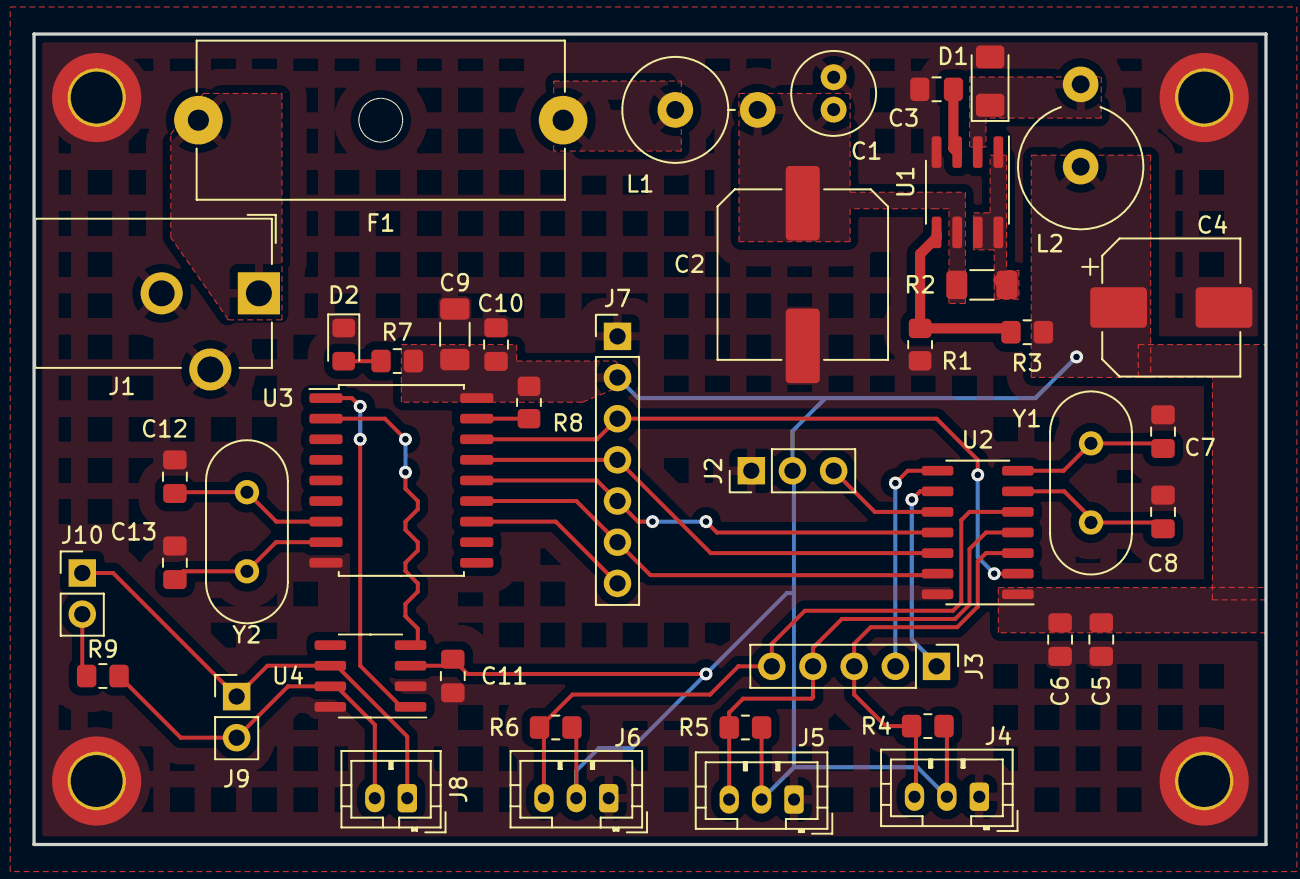
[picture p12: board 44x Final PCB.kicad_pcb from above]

Board: 2 copper layers, 76.0 x 50.0 mm, 47 parts (0 on the bottom side), 31 nets.

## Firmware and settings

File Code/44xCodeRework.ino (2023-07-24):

/*
Team 15 Chain stretch monitor Updated
2022-2023
Corbin: Calculation part
Tianhao: CAN transmission part
*/

/*
Open the code with Arduino IDE 1.
Set the environment: https://github.com/SpenceKonde/megaTinyCore
Reference: https://www.electronics-lab.com/project/getting-started-with-the-new-attiny-chips-programming-the-microchips-0-series-and-1-series-attiny-with-the-arduino-ide/
*/

#include <SPI.h>
#include <mcp_can.h> // source from: https://github.com/Seeed-Studio/Seeed_Arduino_CAN/tree/old
#include <Wire.h>


#define Uh_Oh 7  //chain too long!

// CAN VARIABLE
unsigned char stmp[14] {0, 0, 0, 0, 0, 0, 0, 0, 0, 0, 0, 0, 0, 0};

//Microcontroller VARIABLE
int OuterL = A5; // PWM
int InnerIR = A6; // ASYNC INTERRUPT
int OuterR = A7;

int Chainlength = 0;
const int exp_length = 6; // need to be changed according to chain model


// ------THE DECLARATION ZONE
float percent_error = 1.03;

unsigned long rightNow = micros(); //(current time)
const unsigned long TimeKeeper = 1000000; //1s -> 1,000,000 us
unsigned long Timelastseen = 0;

//Speed sensor time variables
unsigned long Time1 = 0; //(last time IR beam was “seen”)
unsigned long Time2 = 0; //(most recent “sighting” time of beam)

//Outer sensor time variables
unsigned long TimeAtR = 0;
unsigned long TimeAtL = 0;
unsigned long TimeLROffset = 0;

unsigned long howlong; //(“length” of time since most recent link)

bool chainStateSpeed = 0;
bool chainStateSpeedOld = 0;
bool chainStateLeft = 0;
bool chainStateLeftOld = 0;
bool chainStateRight = 0;
bool chainStateRightOld = 0;
bool beenawhile = 0;

//  NEW MEAT AND POTATOES VALS
float chainSpeed = 0; //in um/us
unsigned long offset = 0; //in um
long Total_Length = 0; //150um + offset
long IdealLength = 152; //38um*4 links

MCP_CAN CAN(SS);

void setup()
{
  pinMode(OuterL, INPUT);
  pinMode(OuterR, INPUT);
  pinMode(InnerIR, INPUT);
 
  pinMode(SS, OUTPUT);
    
  while (CAN_OK != CAN.begin(CAN_500KBPS))
  {
      Serial.println("CAN BUS init Failed");
      delay(100);
  }
  Serial.println("CAN BUS Shield Init OK!");
}

void loop()
{ 
  ///Getting chain states
  chainStateSpeed = digitalRead(InnerIR);
  chainStateRight = digitalRead(OuterR);
  chainStateLeft = digitalRead(OuterL);
  
  // Get deltaTime between OuterR and OuterL
  if (chainStateLeft == 1 && (chainStateLeft!=chainStateLeftOld)) {
    TimeAtL = micros();
    Timelastseen = micros(); //used to know if chain is likely outta here/stopped...
  }
  if (chainStateRight == 1 && (chainStateRight!=chainStateRightOld)) {
    TimeAtR = micros();
    Timelastseen = micros(); //...so that old sample thrown out if so
  }
  if (TimeAtR != 0 && TimeAtL != 0) {
    //both have a reading!
    TimeLROffset = abs(TimeAtL - TimeAtR);
  }

  // Calculate Speed from InnerIR
  if (chainStateSpeed != chainStateSpeedOld) {
    if(chainStateSpeed==1){
      Time1 = micros();
    }
    if(chainStateSpeed==0){
      Time2 = micros();
      howlong = Time2-Time1; //finding how long it took to travel 1000um
    }
    
    //situation where chain likely stopped (1000 may be too small)
    if (howlong > TimeKeeper) {
      chainSpeed = 0;
    }
    //situation where chain probably isnt stopped
    else {
      chainSpeed = 1000.0/howlong; // 1um / howlong(us)
    }
    
    stmp[0] = (howlong & 0xff000000UL) >> 24; //used for CAN troubleshooting
    stmp[1] = (howlong & 0x00ff0000UL) >> 16;
    stmp[2] = (howlong & 0x0000ff00UL) >> 8;
    stmp[3] = (howlong & 0x000000ffUL);

	offset = ((TimeLROffset * 1000) / howlong); // us x (um/us)

    if (chainSpeed != 0){
      stmp[4] = (TimeLROffset & 0xff000000UL) >> 24;
      stmp[5] = (TimeLROffset & 0x00ff0000UL) >> 16;
      stmp[6] = (TimeLROffset & 0x0000ff00UL) >> 8;
      stmp[7] = (TimeLROffset & 0x000000ffUL);
	  
      stmp[8] = (offset & 0xff000000UL) >> 24;
      stmp[9] = (offset & 0x00ff0000UL) >> 16;
      stmp[10] = (offset & 0x0000ff00UL) >> 8;
      stmp[11] = (offset & 0x000000ffUL);

      // if (Total_Length > IdealLength*percent_error) { //IdealLength = 152000um, percent_error is 1.03 is 3%
      //   //digitalWrite(Uh_Oh, HIGH);
      //   stmp[3] = 199; // send 199 if chain needs to be replaced
      // }
      // else{
      //   stmp[3] = 200; // send 200 if chain is good
      // }

      // TimeLROffset = 0; //reset
      // chainSpeed = 0;   //reset
    }
    //   else{
    //   Total_Length = 0;
    //   stmp[2] = 0;
    // }
  }


  // if(abs(micros()-Timelastseen)>TimeKeeper){ //again, 1000 may be too big
  //   beenawhile = 1;
  // }
  // if(abs(micros()-Timelastseen)<TimeKeeper){
  //   beenawhile = 0;
  // }
  // //this section is to make sure we aren't holding onto "outdated" info for LR stuff
  // if(beenawhile==1){
  //   chainSpeed = 0;
  //   TimeLROffset = 0;
  // }
  

  chainStateSpeedOld = chainStateSpeed;
  chainStateRightOld = chainStateRight;
  chainStateLeftOld = chainStateLeft;
  
  
  // Transmit part (CAN)
  CAN.sendMsgBuf(0x15, 0, 14, stmp);
  //delay(500);
}

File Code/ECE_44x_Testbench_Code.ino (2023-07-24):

#include <AccelStepper.h>

// Define the number of steps for a full rotation
const int SPR = 200;    //Steps per Revolution
const int DIST = 20;    //Number of Rotations per direction per cycle
const int MAXSPEED = 4;  //Rotations per second
const int ACCEL = 4;     //Rotations per second per second

const int interruptPin = 7;
const int EnablePin = 9;
const int StepPin = 11;	
const int DirPin = 10;

bool motor_run = false;

// Initialize the stepper motor object with the pins used
AccelStepper stepper(AccelStepper::DRIVER, StepPin, DirPin);

void Motor_Switch();

void setup() {
  // put your setup code here, to run once:
  pinMode(EnablePin, OUTPUT);																		//nnfjfjkjlfjkj fkj f
  pinMode(interruptPin, INPUT);																		//nnfjfjkjlfjkj fkj f
  digitalWrite(EnablePin, LOW);																		//nnfjfjkjlfjkj fkj f
  attachInterrupt(digitalPinToInterrupt(interruptPin), Motor_Switch, FALLING);
  stepper.setMaxSpeed(MAXSPEED * SPR);																//nnfjfjkjlfjkj fkj f
  stepper.setAcceleration(ACCEL * SPR);																//nnfjfjkjlfjkj fkj f
}				

void Motor_Switch() {
  motor_run = !motor_run;
}

void loop() {
  if (motor_run) {
    digitalWrite(EnablePin, LOW);
    // Rotate the motor all the way in the opposite direction
    stepper.move(SPR * DIST);
    stepper.runToPosition();
    
    // Pause for one second
    delay(500);
    
    // Rotate the motor all the way in the opposite direction
    stepper.move(-SPR * DIST);				//nnfjfjkjlfjkj fkj f
    stepper.runToPosition();				//nnfjfjkjlfjkj fkj f
    
    // Pause for one second
    delay(500);
  } else {
    digitalWrite(EnablePin, HIGH);
  }
}
